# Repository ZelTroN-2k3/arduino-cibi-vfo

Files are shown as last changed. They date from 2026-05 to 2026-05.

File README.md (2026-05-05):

This Arduino code aims to drive a DDS and a Display in order to replace analog oscillators in old citizen band  transceivers.

# Parts
- [Arduino nano R3](doc/nano.png) with new bootloader (optiboot_atmega328.hex)
- OLED display SSD1306 128x64 0.96" IIC
- a Rotary encoder with button
- A DDS [si5351A](doc/Si5351-B.pdf) (3 outputs)

# Principles
## Basic principles
A rotary encoder with button is used.
- turning the encoder will adjust the frequency.
- clicking the encoder button will change the frequency step

Below it the working principle:

```mermaid
graph TD;
A[Start]-->B(Setup display);
B-->C(Setup pin);
C-->D(Setup DDS);
D-->E{Loop - Key press interrupt?}
E-->|interrupt|F(Update Display)
F-->G{Freq. changed?}
G-->|No|E
G-->|Yes|H(Update DDS)
H-->E
```
## Advanced explanations

- Modulation is read from the modulation selector and wired to D8, D9, D10, D11, D12 in order to adjust VFO and FI depending on the modulation type. This is mainly because of USB and LSB modes with are requiring +/- 2.5kHz shifts.
- TX is read from the mike plug on D5 to activate the FI oscillator upon TX only.
- The old band selector is re-used to switch between : 
* configuration mode (wired to D6).
* transverter mode (wired to D7) : TO BE DONE, for now tranceiver mode as below.
* tranceiver mode which is the default mode when neither D6 and D7 are selected
- finally a small S-meter is implemented using analog input A3
- a RX clarifier is built reusing front potentiometers
- an "increment" mode is built when setting 'CH9' on the front panel. In this tranceiver mode, step is always 5kHz, and pressing the rotary button performs a scan search. When a strong signal is found, the scan stops.

# Compilation

## Retrieve the source code using git

git clone git@gitlab.com:croutor/arduino-cibi-vfo.git

cd arduino-cibi-vfo

git submodule update --init --recursive

## Retrieve the source code without git

Download https://gitlab.com/croutor/arduino-cibi-vfo/-/archive/develop/arduino-cibi-vfo-develop.zip

Unzip it

Download https://github.com/pavelmc/Si5351mcu/archive/refs/heads/master.zip

Unzip it in arduino-cibi-vfo/lib/Si5351mcu 's folder

## IDE setup

This project is using [Microsoft Visual Studio Code](https://code.visualstudio.com/) with [PlatformIO IDE](https://platformio.org/platformio-ide)'s plugin.

## Building

Terminal -> Run Task ->PlatformIO: Build

## Upload on arduino

Terminal -> Run Task ->PlatformIO: Upload

# Wiring
Referring to [vfo.h](/include/vfo.h) and [input.cpp](/src/input.cpp):
* D12 = INPUT CW (active high or low depending on compilation flag INPUT_MODULATION_ACTIVE_HIGH)
* D11 = INPUT AM (active high or low depending on compilation flag INPUT_MODULATION_ACTIVE_HIGH)
* D10 = INPUT FM (active high or low depending on compilation flag INPUT_MODULATION_ACTIVE_HIGH)
* D9 = INPUT USB (active high or low depending on compilation flag INPUT_MODULATION_ACTIVE_HIGH)
* D8 = INPUT LSB (active high or low depending on compilation flag INPUT_MODULATION_ACTIVE_HIGH)
* D7 = (Unused) TRANSVERT MENU (active low)
* D6 = CONFIG MENU (active low)
* D5 = TX (active low)
* D4 = button pin (active low)
* D3 = Rotary encoder A pin
* D2 = Rotary encoder B pin
* A1 = Step/increment mode (active low)
* A2 = clarifier input (analog 0-5V)
* A3 = s-meter input (analog 0-5V)
* A4 = IIC SDA
* A5 = IIC SCL

DDS output on si5351:
* FI(10.695MHz+/-2.5kHz) = CLK0
* VFO(var) = CLK2

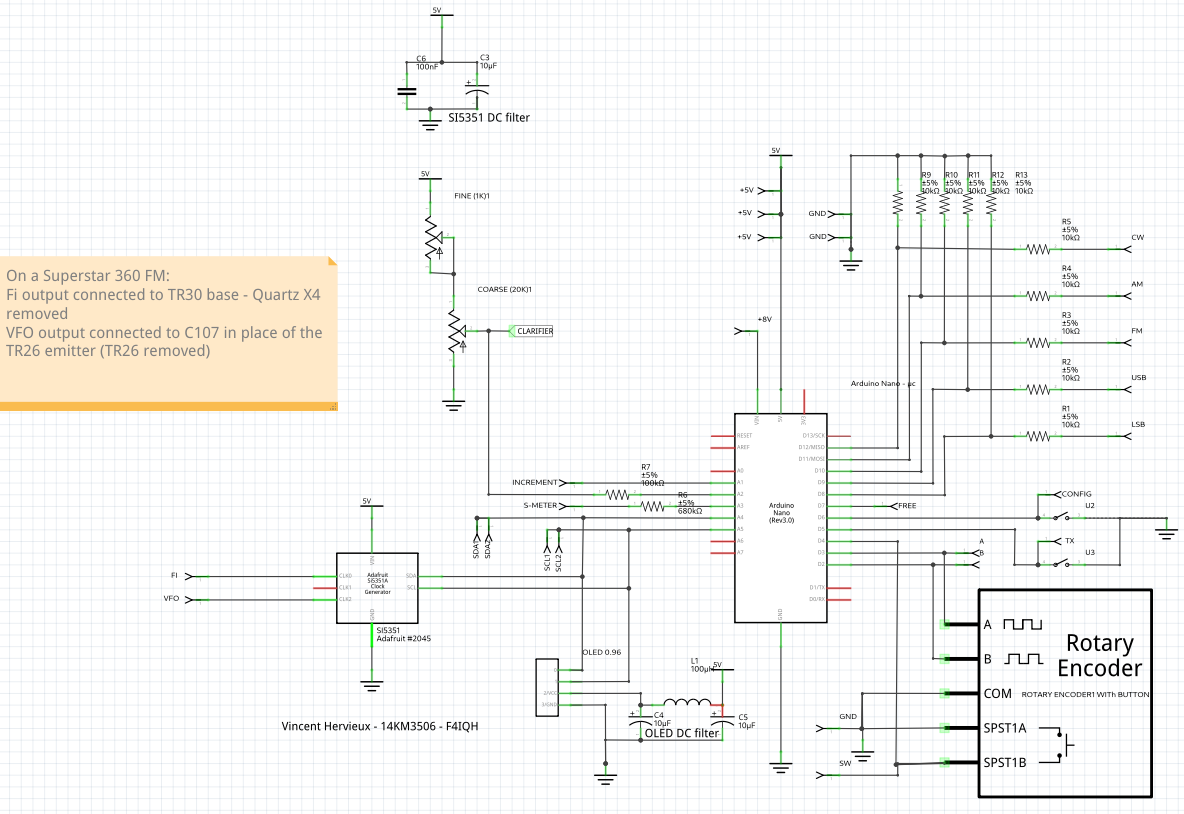
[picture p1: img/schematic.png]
Schematic


# Display
Main menu:
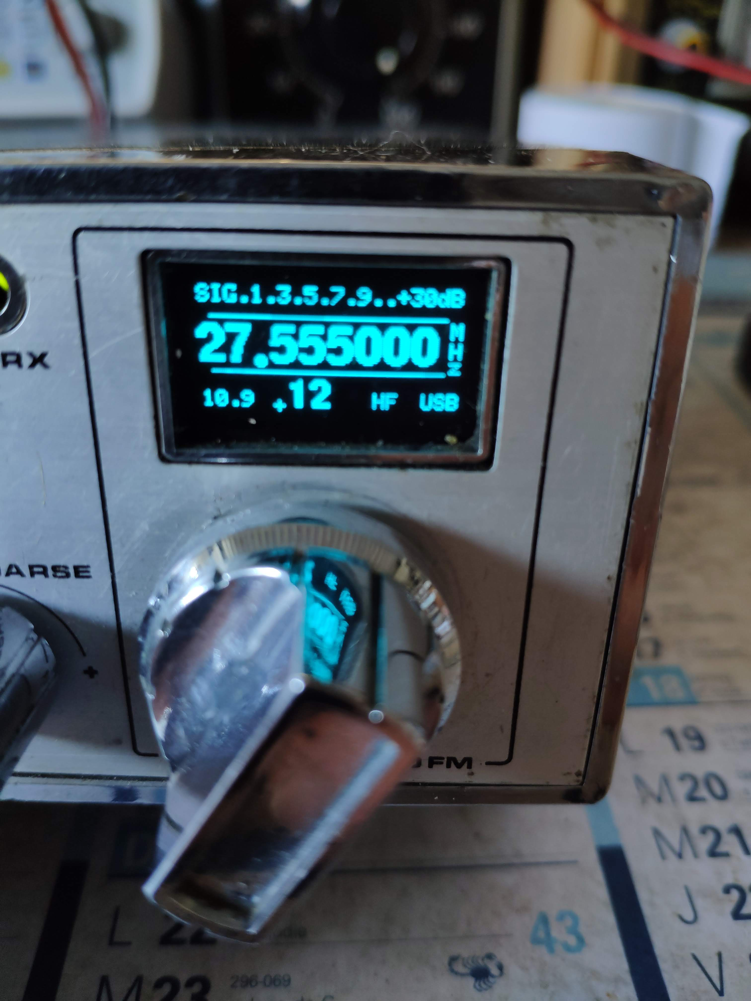
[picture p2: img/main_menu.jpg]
Main menu

Main menu step frequencies:
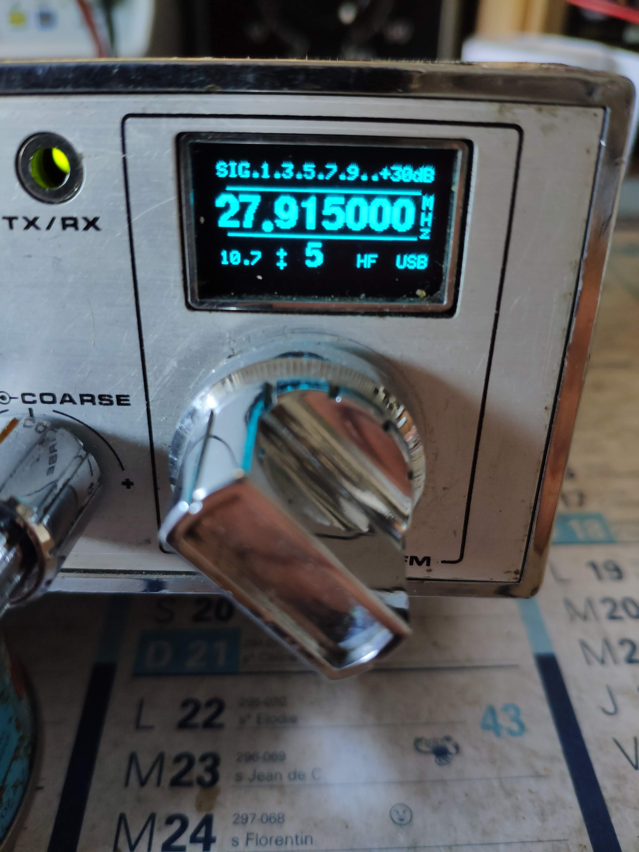
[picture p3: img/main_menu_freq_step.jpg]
Main menu frequency step

Main menu changing frequencies by digit:https://code.visualstudio.com/

Configuration menu aims to adjust some user settings / adjustements:
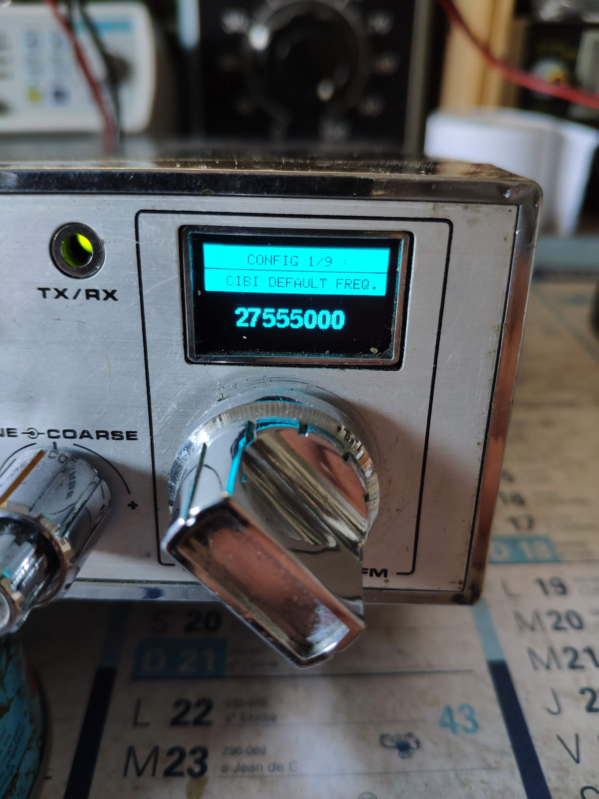
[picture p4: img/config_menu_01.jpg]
Config menu 01
 
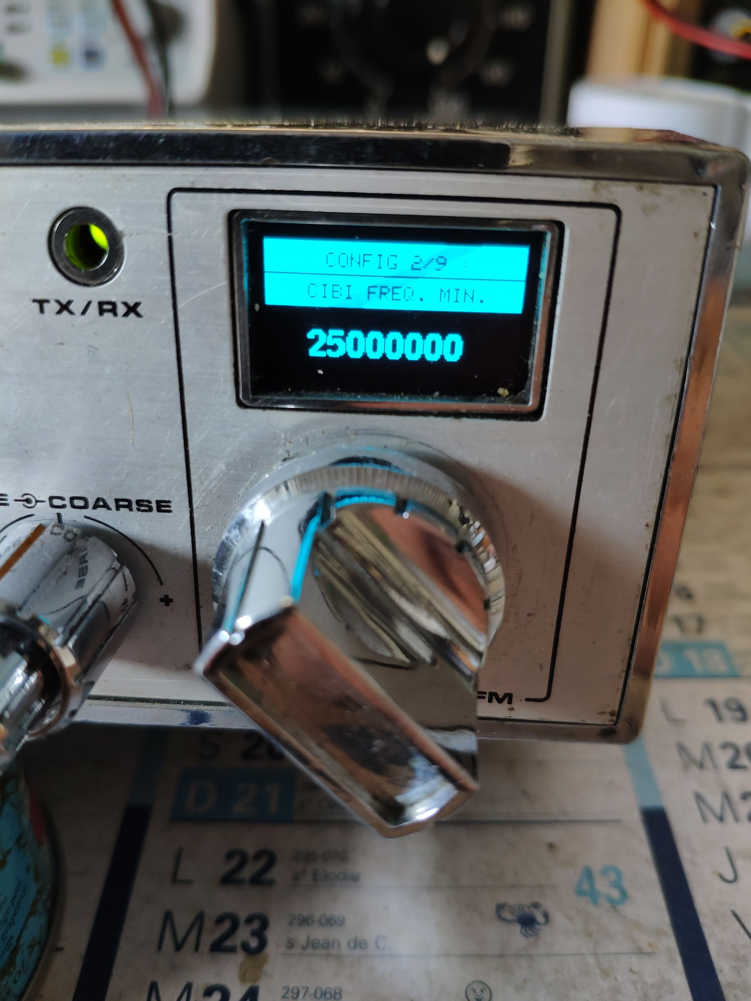
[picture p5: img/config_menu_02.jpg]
Config menu 02
 
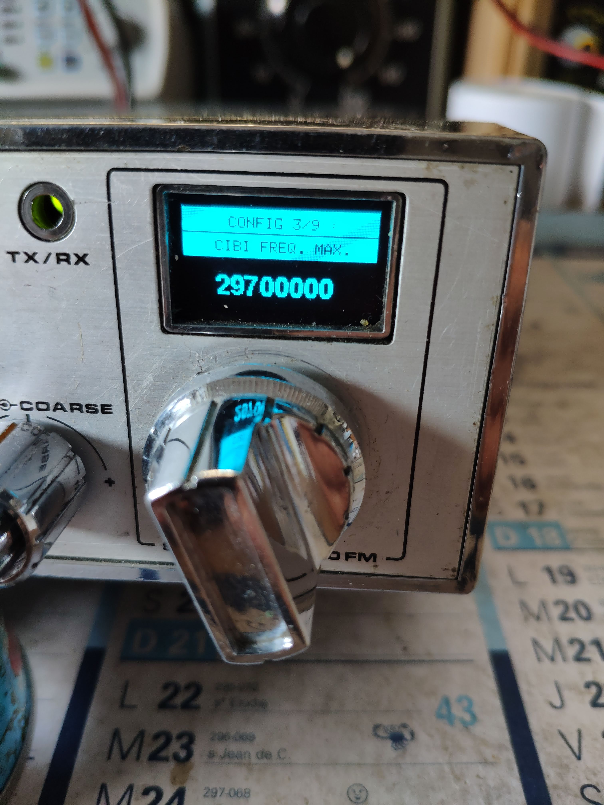
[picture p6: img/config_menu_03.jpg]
Config menu 03
 
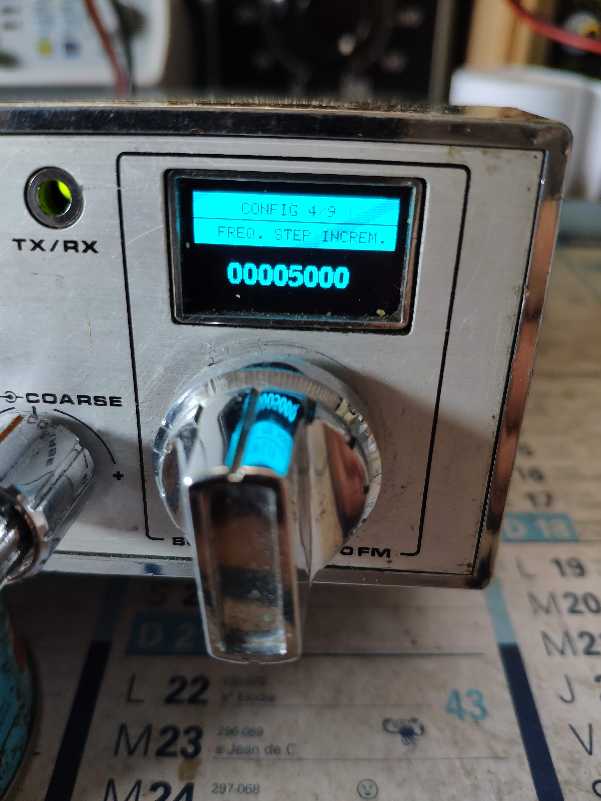
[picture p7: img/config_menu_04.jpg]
Config menu 04
 https://github.com/pavelmc/Si5351mcu/archive/refs/heads/master.zip

# Demo

Video explaining the project

Video demo (https://www.youtube.com/watch?v=91tv6xmkw9M)

# Integration in a Superstar 360 FM

C107 is unplugged from the TR26 emitter first. And then the DDS VFO output is connected to the base of TR27 via the C107 capacitor.

The X4 quartz (10.695MHz) is removed and the DDS FI output is connected to the base of TR30 via an additionnal 10pF capacitor.

TX input has to be connected to the pin of the microphone plug which is grounded while transmitting.

Increment input is connected to the CH9 switch.

Band selector is diconnected from the main board. Its center is grounded. Config's in put is connected to B and Transvert's input is connected to C.

Note that Transvert mode is UNUSED as it is not implemented, so finally you could also wire: Nothing on A, Config on B, and Increment on C.

S-meter input is connected on the Smeter (of course), on the S507 switch side.

Clarifier potentiometers (fine and coarse) are totally disconnected from the main board, and rewired as shown in the schematic

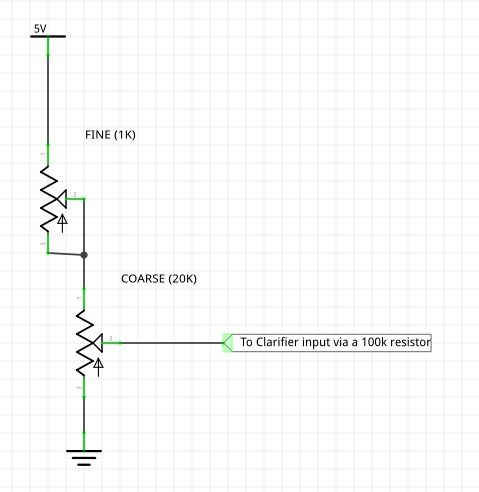
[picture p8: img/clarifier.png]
Clarifier


For the modulations, you need to connect D8, D9, D10, D11, D12 to the cibi tranceiver's modulation selector. Resistors bridges are protecting the inputs from the 8Volts.

# Credits

This project is using some external libraries:

- [U8G2 for the diplay](https://github.com/olikraus/u8g2)

- [Si5351mcu to Drive the DDS](https://github.com/pavelmc/Si5351mcu)

- [ClickEncoder for the rotary encoder](https://github.com/soligen2010/encoder)

- [TimerOne](https://playground.arduino.cc/Code/Timer1/)

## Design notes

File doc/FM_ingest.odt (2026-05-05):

https://www.youtube.com/watch?v=vxVdb2T36N8

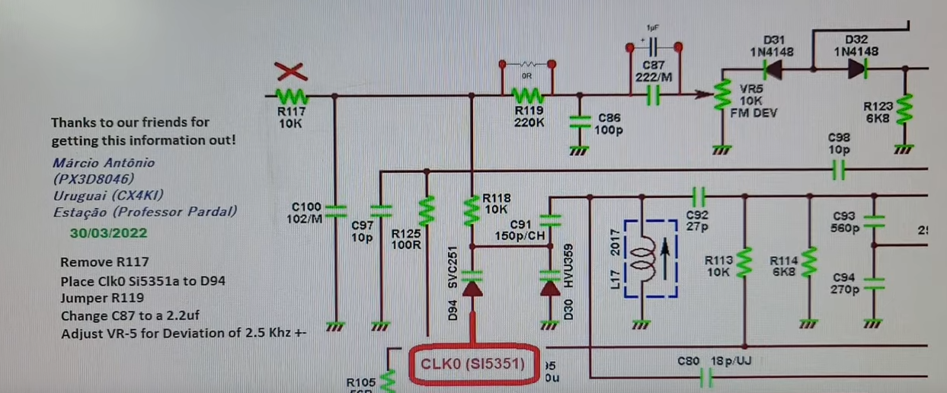
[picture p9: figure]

360Fm Cobra 148GTL

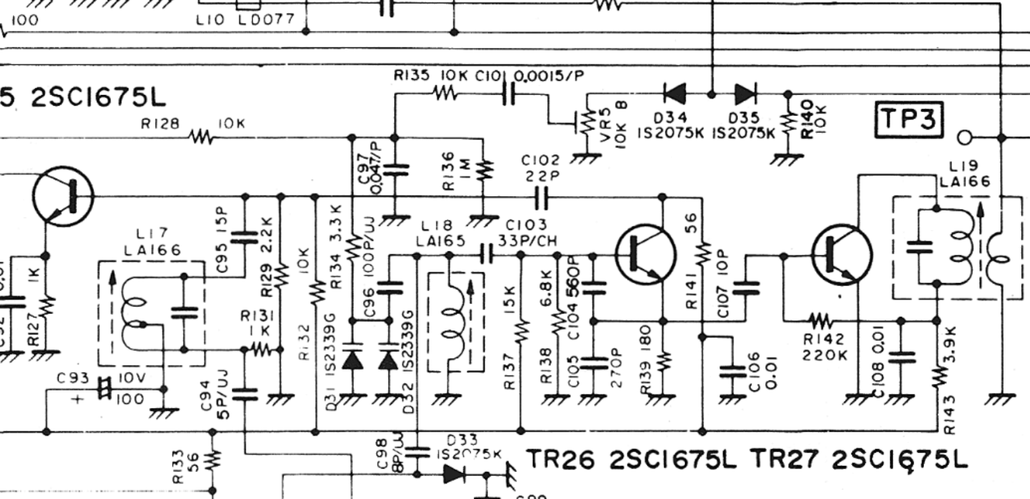
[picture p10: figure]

déssouder l’anode de D31 et injecter CLK0 dessus

déssouder R128

shunter R135

remplacer C101 par une capa de 1µF

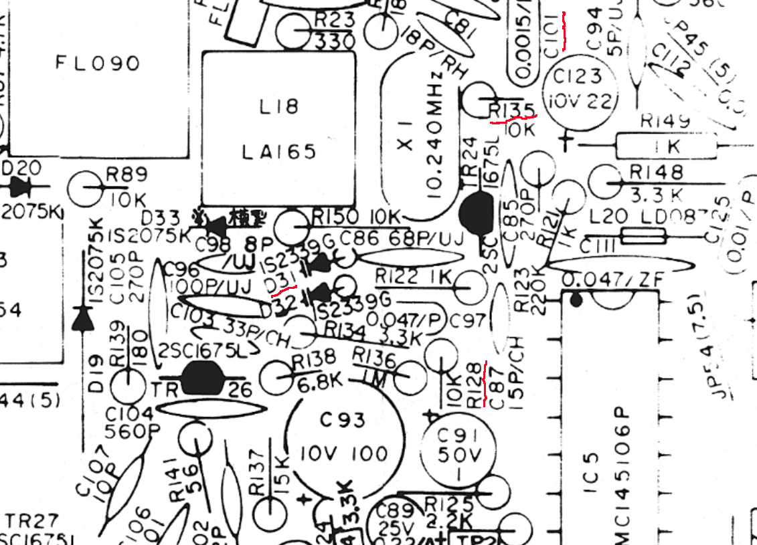
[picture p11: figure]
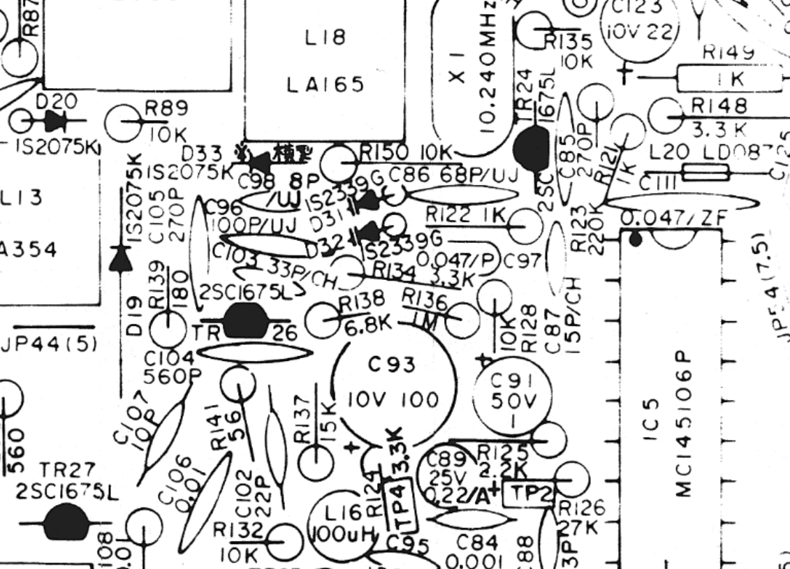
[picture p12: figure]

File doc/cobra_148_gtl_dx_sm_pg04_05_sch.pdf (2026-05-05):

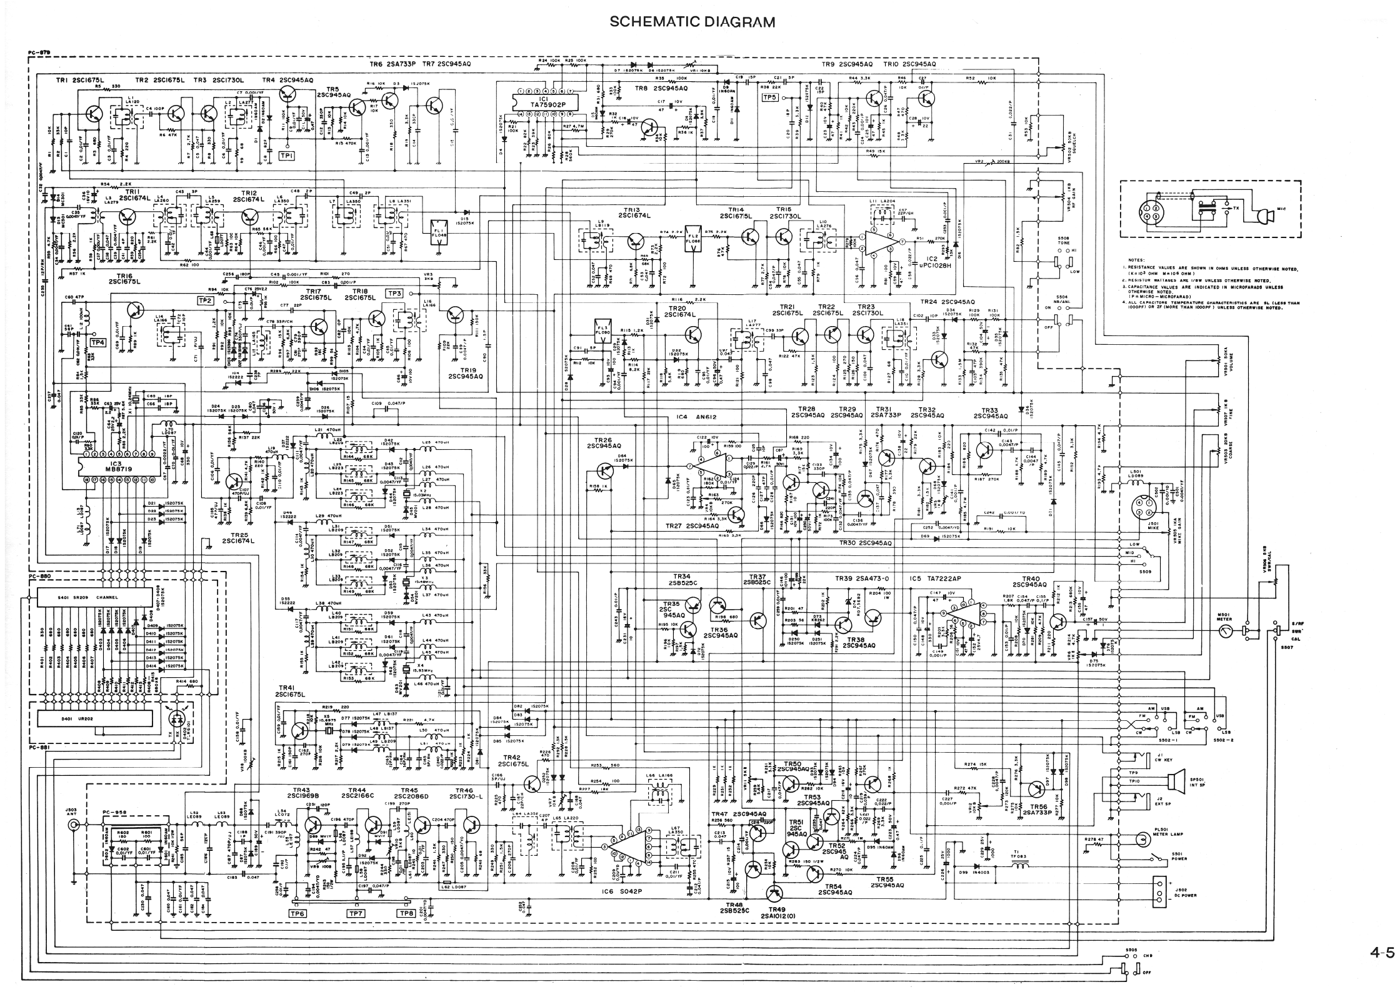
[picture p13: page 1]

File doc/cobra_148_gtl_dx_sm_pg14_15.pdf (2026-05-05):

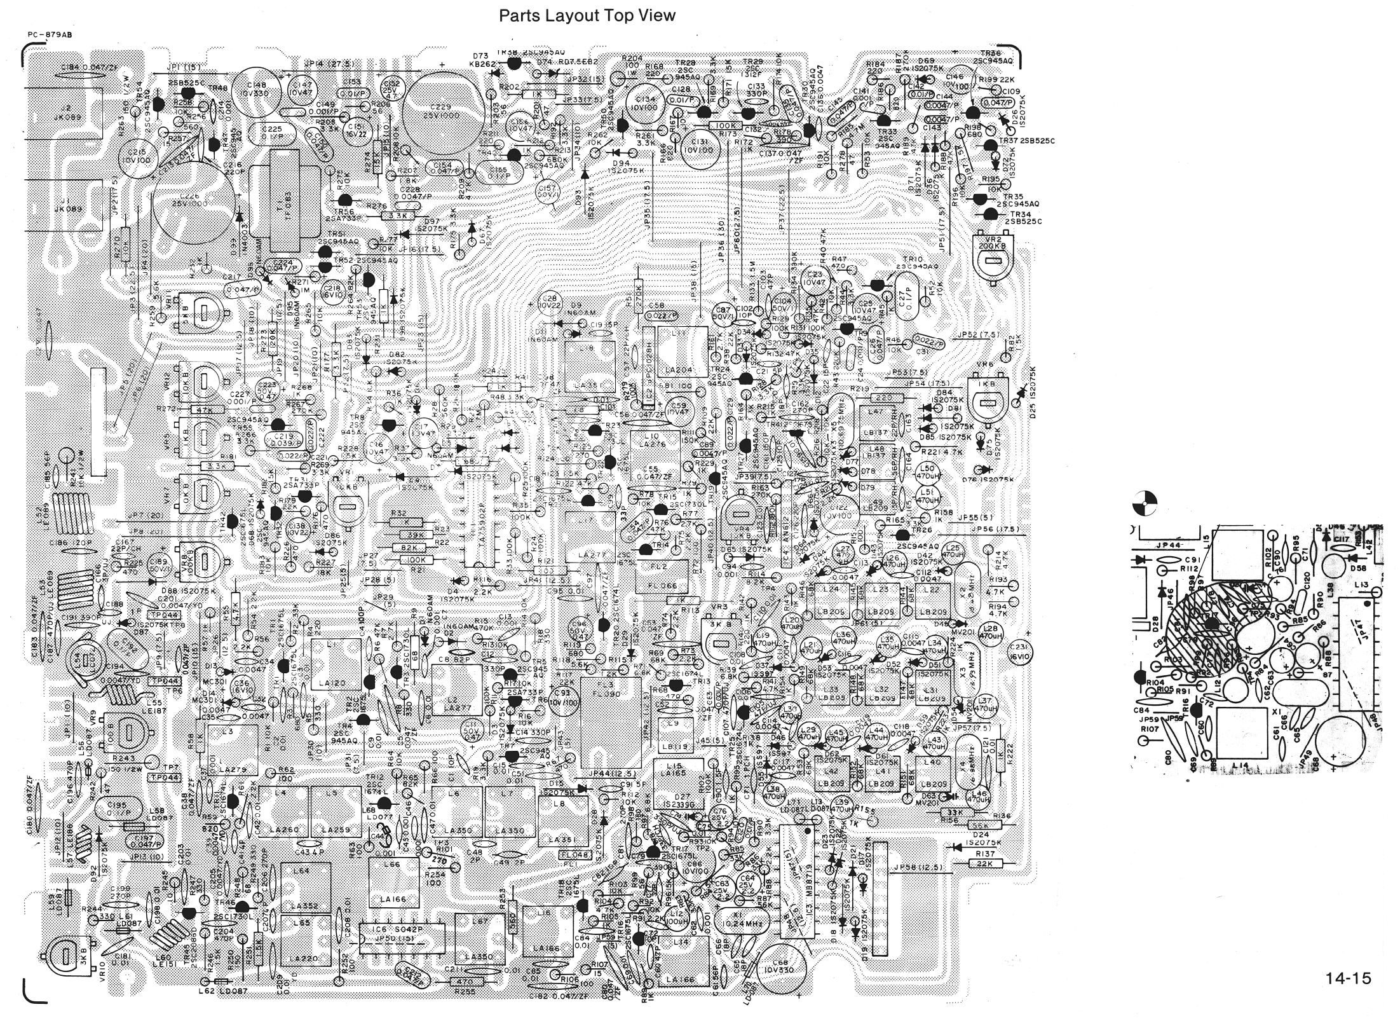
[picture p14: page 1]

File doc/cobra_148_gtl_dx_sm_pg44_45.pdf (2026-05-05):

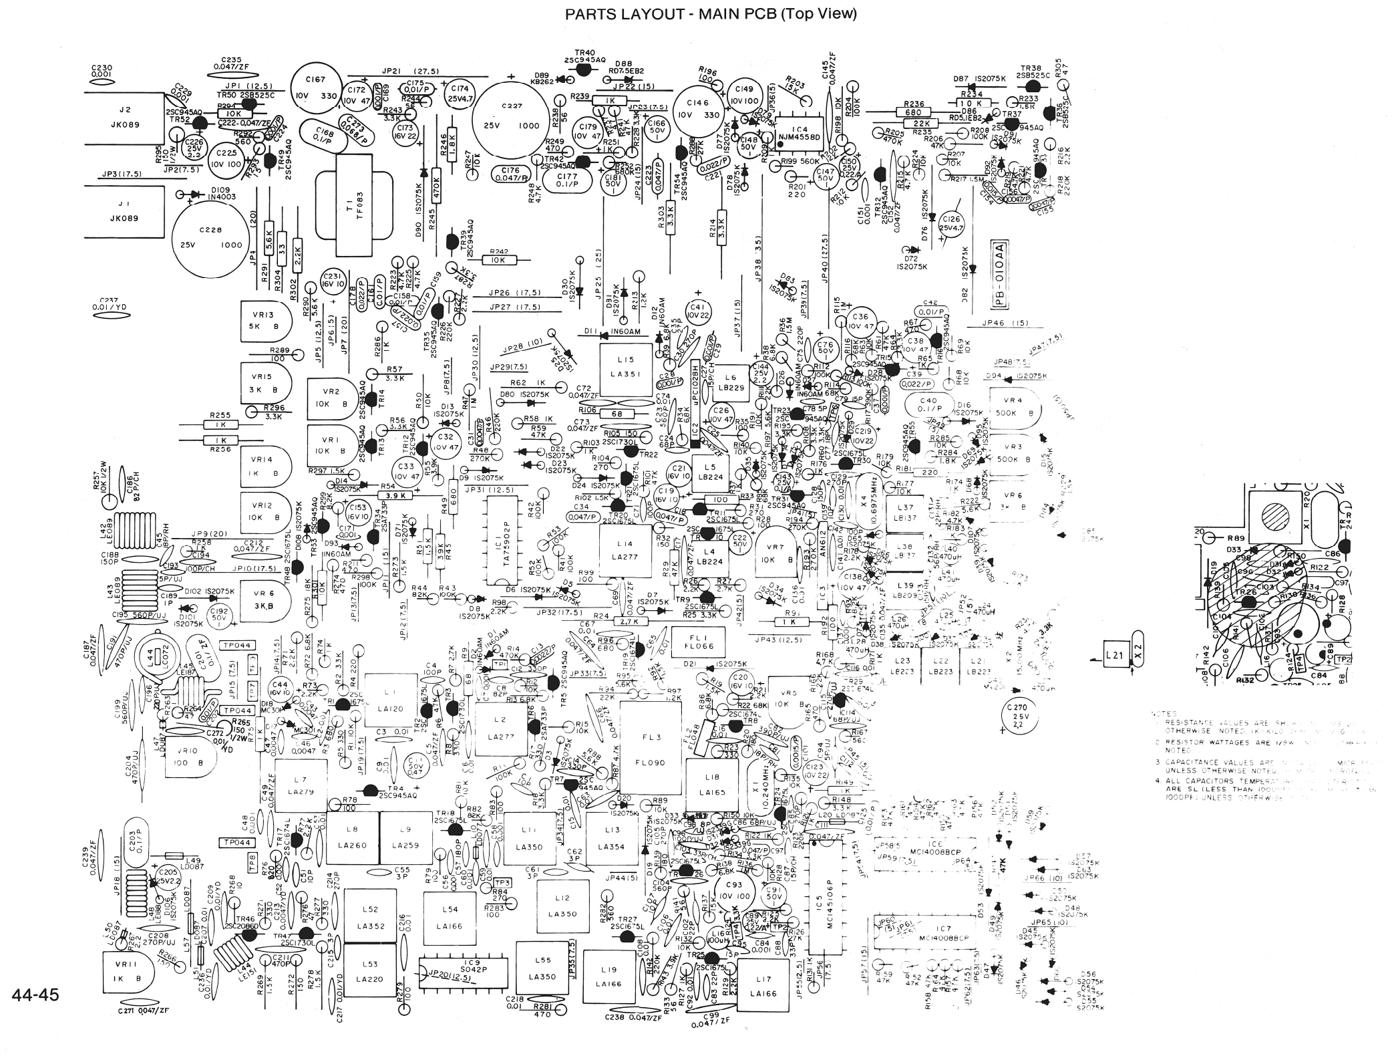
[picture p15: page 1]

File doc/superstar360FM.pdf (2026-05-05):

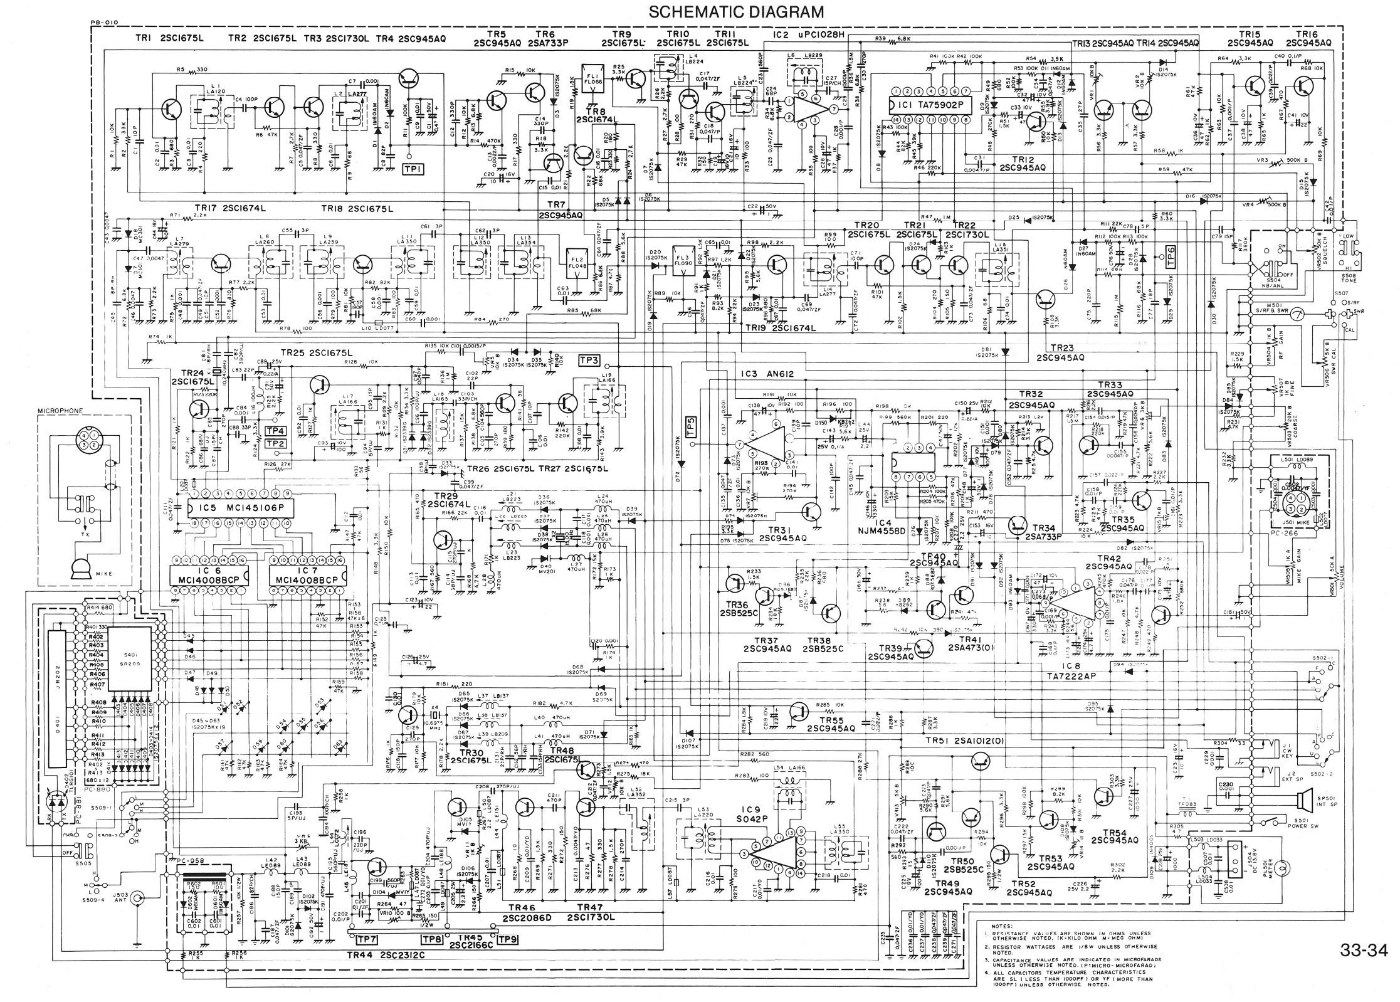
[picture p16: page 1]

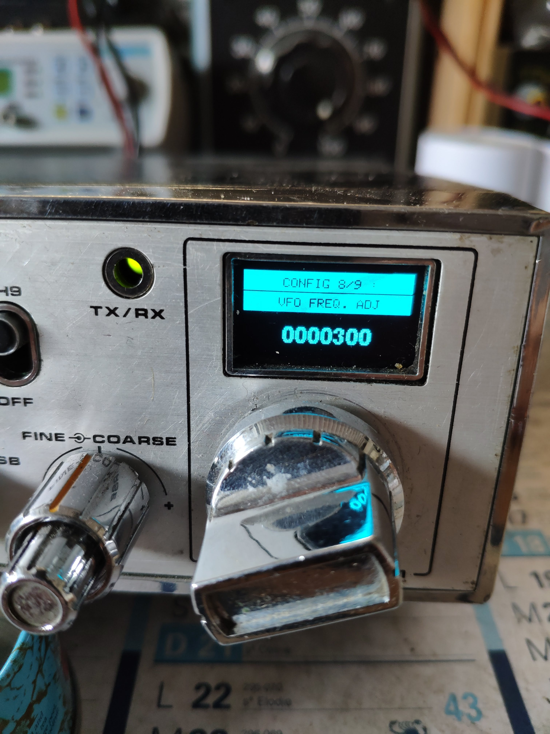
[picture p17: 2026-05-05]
img/config_menu_08.jpg

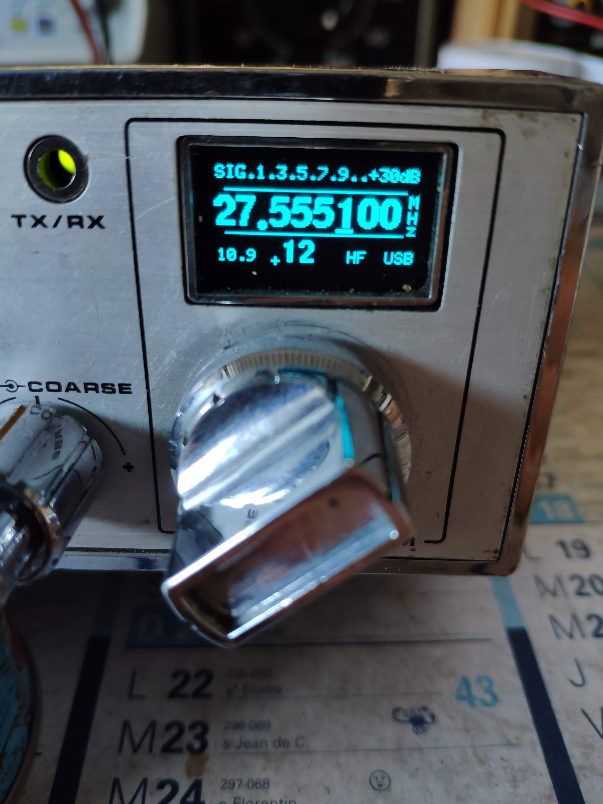
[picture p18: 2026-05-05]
img/main_menu_digit_selection.jpg

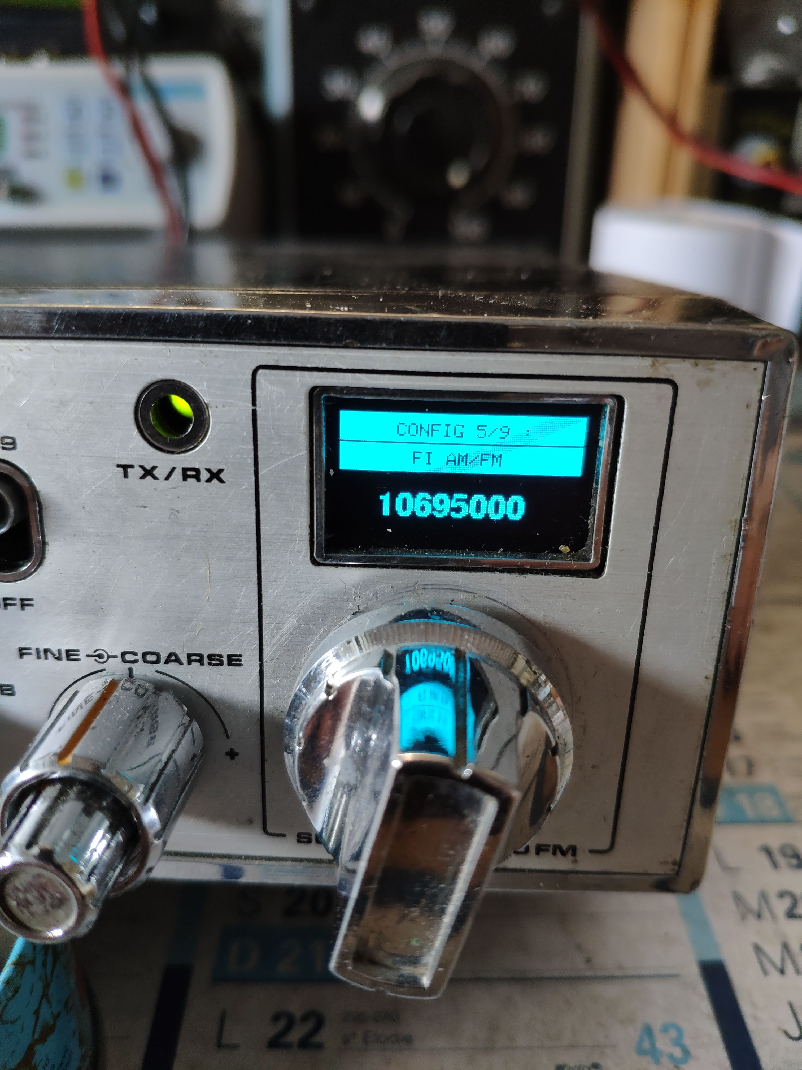
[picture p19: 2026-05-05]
img/config_menu_05.jpg

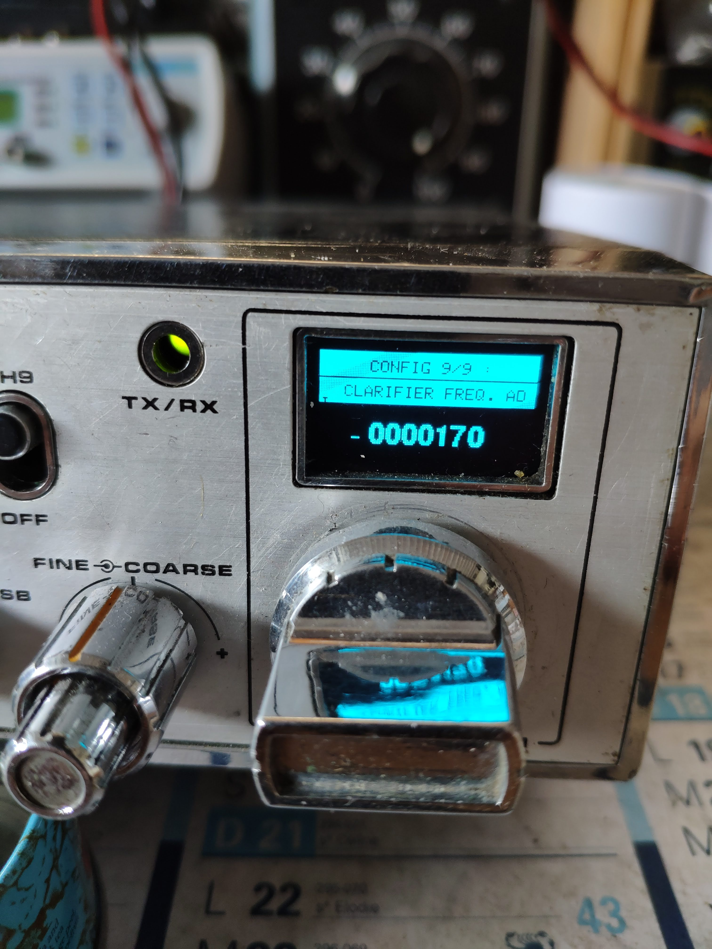
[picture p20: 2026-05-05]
img/config_menu_09.jpg

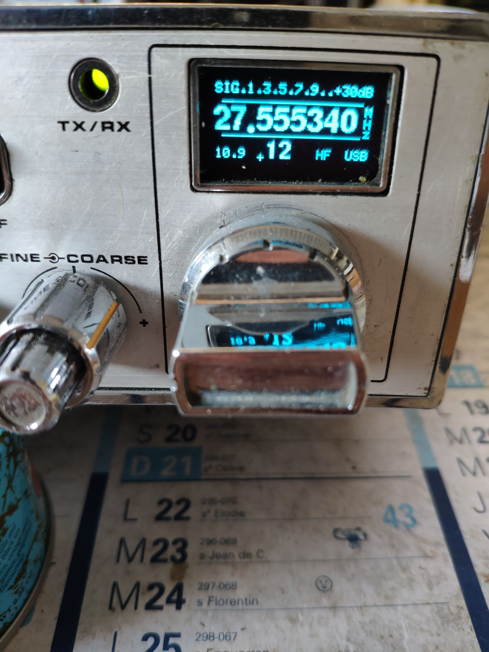
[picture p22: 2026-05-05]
img/main_menu_clarifier_coarse.jpg

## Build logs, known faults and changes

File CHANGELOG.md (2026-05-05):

# Changelog
All notable changes to this project will be documented in this file.

The format is based on [Keep a Changelog](https://keepachangelog.com/en/1.0.0/),
and this project adheres to [Semantic Versioning](https://semver.org/spec/v2.0.0.html).

## Current version
- add step increment mode. Increment can be set in config menu
- add scan feature in step increment mode.

## 2.1.0 - 2019-08-17
- enable FI in Rx CW
- change DDS's PLL frequency
- add clarifier offset feature

## 2.0.0 - 2019-07-29
- add RX clarifier feature
- add VFO offset feature
- add S-meter feature
- heavy refactorisation to introduce application modes config/cibi/transverter
- roll back to Adafruit si5351, modified to enable/disable output one by one

## 1.1.0 - 2019-05-14 (etherkit si5351)
- change si5351 library for one supporting: si5351B + allowing to select output one by one:
https://github.com/etherkit/Si5351Arduino

## 1.0.0 - 2019-05-02 (first stable version)
- initial creation

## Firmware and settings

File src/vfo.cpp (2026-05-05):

/*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
 * * Redistributions of source code must retain the above copyright
 *   notice, this list of conditions and the following disclaimer.
 * * Redistributions in binary form must reproduce the above copyright
 *   notice, this list of conditions and the following disclaimer in the
 *   documentation and/or other materials provided with the distribution.
 * * Neither the name of the author Vincent Hervieux, nor the
 *   names of its contributors may be used to endorse or promote products
 *   derived from this software without specific prior written permission.
 *
 * THIS SOFTWARE IS PROVIDED BY THE REGENTS AND CONTRIBUTORS ``AS IS'' AND ANY
 * EXPRESS OR IMPLIED WARRANTIES, INCLUDING, BUT NOT LIMITED TO, THE IMPLIED
 * WARRANTIES OF MERCHANTABILITY AND FITNESS FOR A PARTICULAR PURPOSE ARE
 * DISCLAIMED. IN NO EVENT SHALL THE REGENTS AND CONTRIBUTORS BE LIABLE FOR ANY
 * DIRECT, INDIRECT, INCIDENTAL, SPECIAL, EXEMPLARY, OR CONSEQUENTIAL DAMAGES
 * (INCLUDING, BUT NOT LIMITED TO, PROCUREMENT OF SUBSTITUTE GOODS OR SERVICES;
 * LOSS OF USE, DATA, OR PROFITS; OR BUSINESS INTERRUPTION) HOWEVER CAUSED AND
 * ON ANY THEORY OF LIABILITY, WHETHER IN CONTRACT, STRICT LIABILITY, OR TORT
 * (INCLUDING NEGLIGENCE OR OTHERWISE) ARISING IN ANY WAY OUT OF THE USE OF THIS
 * SOFTWARE, EVEN IF ADVISED OF THE POSSIBILITY OF SUCH DAMAGE.
 */

/***
 *** Main entry point
 ***/
#include "cibi.h"
#include "config.h"
#include "dds.h"
#include "display.h"
#include "input.h"
#include "vfo.h"
#ifdef WATCHDOG
#include "watchdog.h"
#endif

/// Globals:
//U8G2_SSD1309_128X64_NONAME0_F_HW_I2C display(U8G2_R0, OLED_RESET, SCL /* A5 */ , SDA /* A4 */); // working with 2.42" only
U8G2_SSD1306_128X64_NONAME_F_HW_I2C display(U8G2_R0, OLED_RESET, SCL /* A5 */ , SDA /* A4 */); // working with 2.42" and 0.96" displays
DDS dds;
Input input;
Config config(input, display, dds);
Cibi cibi(config, input, display, dds);

#ifdef WATCHDOG
wdt_interrupt()
{
#ifdef DEBUG
  Serial.println(F("Arduino Cibi VFO - wdt_interrupt"));
#endif
  config.setCibiFreq(cibi.getCurrentFreq());
}
#endif

/// Arduino setup
void setup()
{
  // 0X3C multiplied by 2 for U8G2
  const static byte I2C_OLED_ADDRESS_ PROGMEM = 0x78;
#ifdef DEBUG
    Serial.begin(9600);
    Serial.println(F("Arduino Cibi VFO - setup - begin"));
#endif
  // initialize the Display I2C address (for the 128x64), force a reset
  display.setI2CAddress(I2C_OLED_ADDRESS_);
  // slow down I2C to 100kHz
  display.setBusClock(100000);
  display.begin();
  display.clear();
  // custom message/bitmap begins here
  display.setFont(u8g2_font_6x10_tr);
  display.setFontRefHeightExtendedText();
  display.setDrawColor(1);
  display.setFontDirection(0);
  display.drawStr(35, 10, "Starting...");
  display.drawStr(12, 50, "arduino-cibi-vfo");
  display.sendBuffer();
  delay(1000);
  // custom message/bitmap ends here
  input.init();
  /* load config from EEPROM */
  config.open();
  /* init DDS crystal */
  dds.init();
  if(0 != config.getVFOAdj())
  {
#ifdef DEBUG
 //   Serial.print(F("Set correction: "));Serial.println(config.getVFOAdj());
#endif
    dds.setOutputCorrection(config.getVFOAdj());
  }
#ifdef DEBUG
    Serial.println(F("Setup - end"));
#endif
#ifdef WATCHDOG
  wdt_enable();
#endif
}

/// Arduino main loop
bool saveConfig = false;
int mode = -1;
void loop()
{

  int new_mode;
  bool update_display = false;
  /* read inputs */
  input.read();
  new_mode = input.getApplicationMode();
  if(mode != new_mode)
  {
    display.clearDisplay();
    mode = new_mode;
    update_display = true;
  }
  switch(mode)
  {
    case Input::CONFIG_MODE:
      config.loop(update_display);
      /* Save config upon exit */
      saveConfig = true;
      break;
#ifdef TRANSVERTER
    case Input::TRANSVERTER_MODE:
#endif
      /* TODO: transverter.loop(update_display) */
    case Input::TRANSCEIVER_MODE:
    default:
      if(saveConfig)
      {
        config.save();
        saveConfig = false;
      }
      cibi.loop(update_display);
      break;
  }
#ifdef WATCHDOG
  wdt_reset();
#endif
}

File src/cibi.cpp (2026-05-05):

/*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
 * * Redistributions of source code must retain the above copyright
 *   notice, this list of conditions and the following disclaimer.
 * * Redistributions in binary form must reproduce the above copyright
 *   notice, this list of conditions and the following disclaimer in the
 *   documentation and/or other materials provided with the distribution.
 * * Neither the name of the author Vincent Hervieux, nor the
 *   names of its contributors may be used to endorse or promote products
 *   derived from this software without specific prior written permission.
 *
 * THIS SOFTWARE IS PROVIDED BY THE REGENTS AND CONTRIBUTORS ``AS IS'' AND ANY
 * EXPRESS OR IMPLIED WARRANTIES, INCLUDING, BUT NOT LIMITED TO, THE IMPLIED
 * WARRANTIES OF MERCHANTABILITY AND FITNESS FOR A PARTICULAR PURPOSE ARE
 * DISCLAIMED. IN NO EVENT SHALL THE REGENTS AND CONTRIBUTORS BE LIABLE FOR ANY
 * DIRECT, INDIRECT, INCIDENTAL, SPECIAL, EXEMPLARY, OR CONSEQUENTIAL DAMAGES
 * (INCLUDING, BUT NOT LIMITED TO, PROCUREMENT OF SUBSTITUTE GOODS OR SERVICES;
 * LOSS OF USE, DATA, OR PROFITS; OR BUSINESS INTERRUPTION) HOWEVER CAUSED AND
 * ON ANY THEORY OF LIABILITY, WHETHER IN CONTRACT, STRICT LIABILITY, OR TORT
 * (INCLUDING NEGLIGENCE OR OTHERWISE) ARISING IN ANY WAY OUT OF THE USE OF THIS
 * SOFTWARE, EVEN IF ADVISED OF THE POSSIBILITY OF SUCH DAMAGE.
 */

#include "cibi.h"
#include "utils.h"
#include "vfo.h"

const int8_t Cibi::cibi_channels[45] PROGMEM = {
    1, 2, 3, 3, 4, 5, 6, 7, 7, 8, 9,
    10, 11, 11, 12, 13, 14, 15, 15, 16, 17, 18, 19, 19,
    20, 21, 22, 23, 24, 25, 26, 27, 28, 29,
    30, 31, 32, 33, 34, 35, 36, 37, 38, 39,
    40};

const bool Cibi::cibi_channels_bis[45] PROGMEM = {
    /* 1- 9*/ false, false, false, true /*3*/, false, false, false, false, true /*7*/, false, false,
    /*10-19*/ false, false, true /*11*/, false, false, false, false, true /*15*/, false, false, false, false, true /*19*/,
    /*20-29*/ false, false, false, false, false, false, false, false, false, false,
    /*30-39*/ false, false, false, false, false, false, false, false, false, false,
    /* 40  */ false};

Cibi::Cibi(Config &_config, Input &_input, U8G2 &_display, DDS &_dds) : config_(_config),
                                                                                    input_(_input),
                                                                                    dds_(_dds),
                                                                                    current_cibi_channel_({.channel = -1,
                                                                                                           .band = CIBI_BAND_UNKNOWN,
                                                                                                           .bis = false}),
                                                                                    current_freq_(0),
                                                                                    freq_change_time_(0),
                                                                                    current_clarifier_(0),
                                                                                    freq_step_(0),
                                                                                    current_cursor_pos_(CURSOR_POS_FREQ_DIG5), // <-- should be a parameter?
                                                                                    current_modulation_(-1),
                                                                                    current_smeter_(0),
                                                                                    current_tx_(false),
                                                                                    scanning_(false)
{
  view_ = new CibiDisplay(_display);
  updateFreqStep(current_cursor_pos_);
}

Cibi::Cibi(const Cibi &_cibi) : config_(_cibi.config_),
                                input_(_cibi.input_),
                                dds_(_cibi.dds_),
                                current_cibi_channel_({.channel = _cibi.current_cibi_channel_.channel,
                                                       .band = _cibi.current_cibi_channel_.band,
                                                       .bis = _cibi.current_cibi_channel_.bis}),
                                current_freq_(_cibi.current_freq_),
                                freq_change_time_(_cibi.freq_change_time_),
                                current_clarifier_(_cibi.current_clarifier_),
                                freq_step_(_cibi.freq_step_),
                                current_cursor_pos_(_cibi.current_cursor_pos_),
                                current_modulation_(_cibi.current_modulation_),
                                current_smeter_(_cibi.current_smeter_),
                                current_tx_(_cibi.current_tx_),
                                scanning_(_cibi.scanning_),
                                view_(_cibi.view_)
{
}

Cibi::~Cibi()
{
  delete view_;
}

int Cibi::getCibiChannel(uint32_t _frequency, Cibi::cibi_channel_t *_channel)
{
  /* Cibi channels */
  /* Pay attention that TX over 28Mhz is reserved for HAM use */
  const static uint16_t FREQ_CIBI_LOW_DAKHZ PROGMEM = 2561;
  const static uint16_t FREQ_CIBI_HIGH_DAKHZ PROGMEM = 2875;
  /* A cibi band is 45 channels:
       - 40 channels
       - 5 'bis' channels: 3,7,11,15,19  */
  const uint16_t CIBI_BAND_DAKHZ PROGMEM = 45;
  /* Round to kHz to compute channels
     * This avoids to get no display of channels
     * in case a fine tuning was made to clarify the voice 
     */
  uint16_t freq_dakhz = _frequency / 10000;
  _channel->channel = -1;
  _channel->band = CIBI_BAND_UNKNOWN;
  _channel->bis = false;
  /* Check if we are not out of Cibi band */
  if (freq_dakhz < FREQ_CIBI_LOW_DAKHZ || freq_dakhz > FREQ_CIBI_HIGH_DAKHZ)
    return -1;

  /* move down band to 0 for computation */
  freq_dakhz -= FREQ_CIBI_LOW_DAKHZ;

  _channel->band = freq_dakhz / CIBI_BAND_DAKHZ;
  /* reuse variable freq_dakhz as index in cibi_channel array, */
  freq_dakhz = freq_dakhz % CIBI_BAND_DAKHZ;
  _channel->channel = pgm_read_byte_near(cibi_channels + freq_dakhz);
  _channel->bis = pgm_read_byte_near(cibi_channels_bis + freq_dakhz);
  return 0;
}
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

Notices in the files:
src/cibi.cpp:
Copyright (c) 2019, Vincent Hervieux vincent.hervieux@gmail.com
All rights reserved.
